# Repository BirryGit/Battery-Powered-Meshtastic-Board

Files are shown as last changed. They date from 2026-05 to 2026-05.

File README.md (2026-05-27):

# Battery-Powered-Meshtastic-Board
This is an ESP-32-S3 powered LoRa board with a battery charger. It has a connected screen and external pins for I2C and power outputs. It has ESD protection.

I want to learn how to make PCBs, and this seemed like a good idea. I wanted to make my first PCB and understand the whole process. I want to get into meshtastic, so this is awesome :)

# BOM
| Name | Purpose | Quantity | Total Cost (USD) | Link | Distributor |
|---|---|---:|---:|---|---|
| PCB | Puts Everything Together | 1 | 22.48 | https://jlcpcb.com  | JLCPCB |
| 10µF | C14 | 1 | 1.48 | https://www.digikey.com/en/mylists/list/BA1MMOEV0W/quote/18716729 | Digikey |
| LTST-C190TBKT | Leds | 3 | 1.73 | https://www.digikey.com/en/mylists/list/BA1MMOEV0W/quote/18716729 | Digikey |
| 5.1K | R1,R2 | 2 | 0.47 | https://www.digikey.com/en/mylists/list/BA1MMOEV0W/quote/18716729 | Digikey |
| 1M | R6 | 1 | 0.47 | https://www.digikey.com/en/mylists/list/BA1MMOEV0W/quote/18716729 | Digikey |
| 200k | R7 | 1 | 0.47 | https://www.digikey.com/en/mylists/list/BA1MMOEV0W/quote/18716729 | Digikey |
| 1k | R9,R10,R11 | 3 | 0.47 | https://www.digikey.com/en/mylists/list/BA1MMOEV0W/quote/18716729 | Digikey |
| BQ24040DSQR | Battery Charger | 1 | 2.85 | https://www.digikey.com/en/mylists/list/BA1MMOEV0W/quote/18716729 | Digikey |
| TLV75801PDRV | Linear Regulator | 1 | 0.93 | https://www.digikey.com/en/mylists/list/BA1MMOEV0W/quote/18716729 | Digikey |
| Buttons | Boot1,Reset1 | 2 | 0.00 | |  |
| ESP32-S3-WROOM-1 | Processor | 1 | 11.76 | https://www.digikey.com/en/mylists/list/BA1MMOEV0W/quote/18716729 | Digikey |
| 0.1µF | C13,C15 | 2 | 0.73 | https://www.digikey.com/en/mylists/list/BA1MMOEV0W/quote/18716729 | Digikey |
| USB4105-GF-A | USB C Port | 1 | 2.40 | https://www.digikey.com/en/mylists/list/BA1MMOEV0W/quote/18716729 | Digikey |
| 10k | R4,R5 | 2 | 0.47 | https://www.digikey.com/en/mylists/list/BA1MMOEV0W/quote/18716729 | Digikey |
| 540 | R8 | 1 | 0.47 | https://www.digikey.com/en/mylists/list/BA1MMOEV0W/quote/18716729 | Digikey |
| ESD7104MUTAG | ESD Protection | 1 | 3.15 | https://www.digikey.com/en/mylists/list/BA1MMOEV0W/quote/18716729 | Digikey |
| 1µF | C9,C10,C11,C12 | 4 | 2.75 | https://www.digikey.com/en/mylists/list/BA1MMOEV0W/quote/18716729 | Digikey |
| Wio-SX1262 | LoRa Module | 1 | 8.58 | https://www.seeedstudio.com/Wio-SX1262-Wireless-Module-p-5981.html | Seeed Studio |

# Pictures





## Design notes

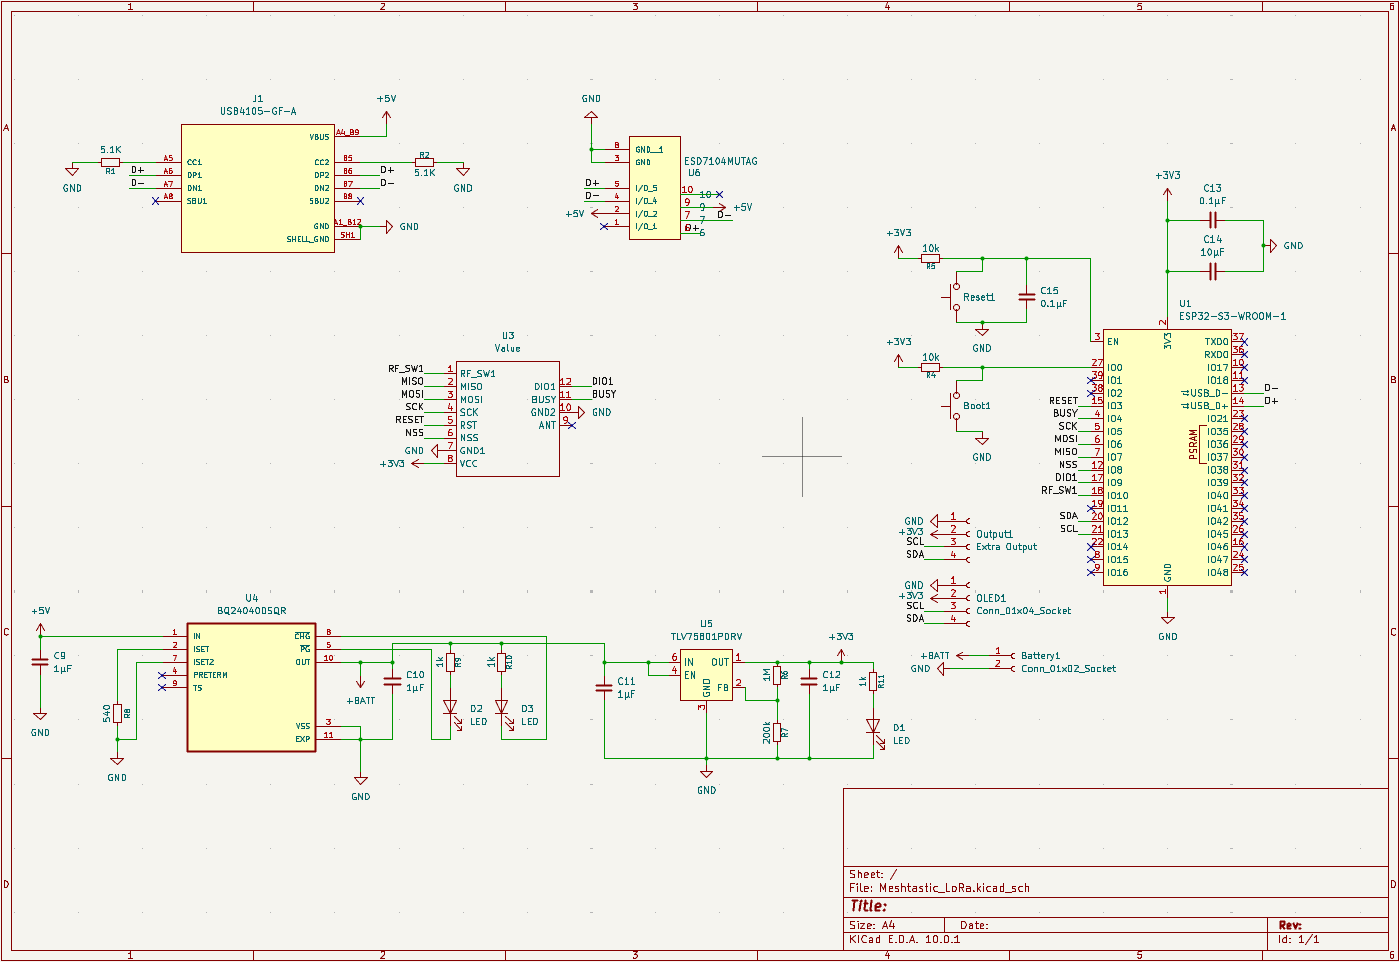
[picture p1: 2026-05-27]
Schematic/Screenshot 2026-05-26 215936.png

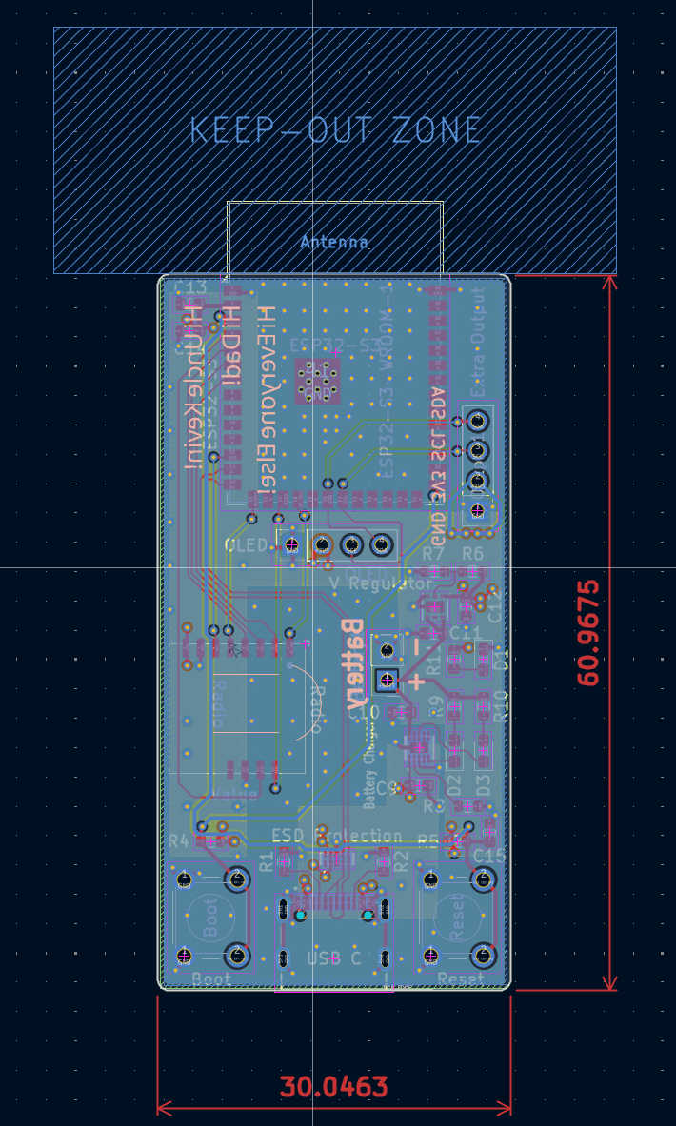
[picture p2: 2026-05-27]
PCB/Screenshot 2026-05-26 220120.png

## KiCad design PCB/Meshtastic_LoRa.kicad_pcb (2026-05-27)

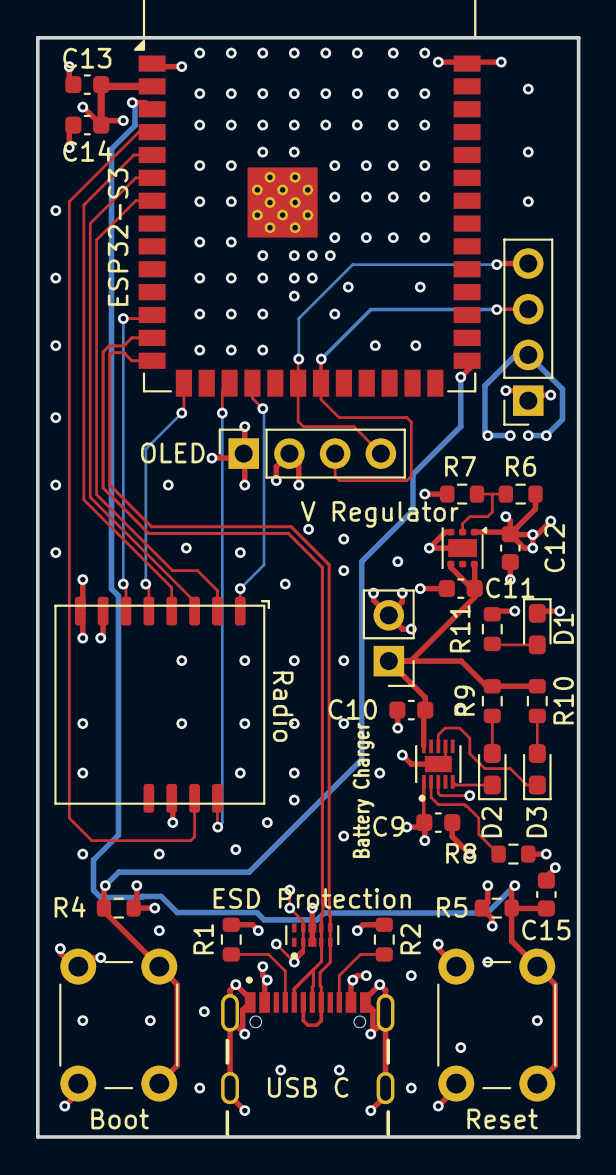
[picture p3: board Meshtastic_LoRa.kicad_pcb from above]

Board: 4 copper layers, 30.0 x 61.1 mm, 31 parts (0 on the bottom side), 27 nets.

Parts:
Battery1: Conn_01x02_Socket; PinHeader_1x02_P2.54mm_Vertical
Battery Charger: BQ24040DSQR; SON40P200X200X80-11N
Boot: SW_Push; SW_PUSH_6mm
C9, C10, C11, C12: 1µF; C_0603_1608Metric
C13, C15: 0.1µF; C_0603_1608Metric
C14: 10µF; C_0603_1608Metric
D1, D2, D3: LED; LED_0603_1608Metric_Pad1.05x0.95mm_HandSolder
ESD Protection: ESD7104MUTAG; IC_ESD7104MUTAG
ESP32-S3: ESP32-S3-WROOM-1
OLED: Conn_01x04_Socket; PinSocket_1x04_P2.54mm_Vertical
Output1: Extra Output; PinSocket_1x04_P2.54mm_Vertical
R1, R2: 5.1K; R_0603_1608Metric
R4, R5: 10k; R_0603_1608Metric
R6: 1M; R_0603_1608Metric
R7: 200k; R_0603_1608Metric
R8: 540; R_0603_1608Metric
R9, R10, R11: 1k; R_0603_1608Metric
Radio: Value; Wio-SX1262 PCB Package
Reset: SW_Push; SW_PUSH_6mm
USB C: USB4105-GF-A; GCT_USB4105-GF-A
V Regulator: TLV75801PDRV; WSON-6-1EP_2x2mm_P0.65mm_EP1x1.6mm

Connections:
+3V3: C12.2, C13.2, C14.2, ESP32-S3.2 (3V3), OLED.2, Output1.2, R4.2, R5.2, R6.1, R11.1, Radio.8 (VCC), V Regulator.1 (OUT)
+5V: Battery Charger.1 (IN), C9.2, ESD Protection.2 (I/O_2), ESD Protection.9, USB C.A4_B9 (VBUS), USB C.B4_A9 (VBUS)
+BATT: Battery1.1, Battery Charger.10 (OUT), C10.2, C11.2, R9.1, R10.1, V Regulator.4 (EN), V Regulator.6 (IN)
/BUSY: ESP32-S3.4 (IO4), Radio.11 (BUSY)
/D+: ESD Protection.5 (I/O_5), ESD Protection.6, ESP32-S3.14 (USB_D+), USB C.A6 (DP1), USB C.B6 (DP2)
/D-: ESD Protection.4 (I/O_4), ESD Protection.7, ESP32-S3.13 (USB_D-), USB C.A7 (DN1), USB C.B7 (DN2)
/DIO1: ESP32-S3.17 (IO9), Radio.12 (DIO1)
/MISO: ESP32-S3.7 (IO7), Radio.2 (MISO)
/MOSI: ESP32-S3.6 (IO6), Radio.3 (MOSI)
/NSS: ESP32-S3.12 (IO8), Radio.6 (NSS)
/RESET: ESP32-S3.15 (IO3), Radio.5 (RST)
/RF_SW1: ESP32-S3.18 (IO10), Radio.1 (RF_SW1)
/SCK: ESP32-S3.5 (IO5), Radio.4 (SCK)
/SCL: ESP32-S3.21 (IO13), OLED.3, Output1.3
/SDA: ESP32-S3.20 (IO12), OLED.4, Output1.4
GND: Battery1.2, Battery Charger.3 (VSS), Battery Charger.7 (ISET2), Battery Charger.11 (EXP), Boot.1, C9.1, C10.1, C11.1, C12.1, C13.1, C14.1, C15.2, D1.1 (K), ESD Protection.3 (GND), ESD Protection.8 (GND__1), ESP32-S3.1 (GND), ESP32-S3.40 (GND), ESP32-S3.41 (GND), OLED.1, Output1.1, R1.1, R2.2, R7.2, R8.2, Radio.7 (GND1), Radio.10 (GND2), Reset.1, USB C.A1_B12 (GND), USB C.B1_A12 (GND), USB C.SH1 (SHELL_GND), USB C.SH2 (SHELL_GND), USB C.SH3 (SHELL_GND), USB C.SH4 (SHELL_GND), V Regulator.3 (GND), V Regulator.7 (GND)
unnamed: D1.2 (A), R11.2
unnamed: D2.2 (A), R9.2
unnamed: Battery Charger.5 (~PG), D2.1 (K)
unnamed: D3.2 (A), R10.2
unnamed: Battery Charger.8 (~CHG), D3.1 (K)
unnamed: R1.2, USB C.A5 (CC1)
unnamed: R2.1, USB C.B5 (CC2)
unnamed: C15.1, ESP32-S3.3 (EN), R5.1, Reset.2
unnamed: Boot.2, ESP32-S3.27 (IO0), R4.1
unnamed: Battery Charger.2 (ISET), R8.1
unnamed: R6.2, R7.1, V Regulator.2 (FB)

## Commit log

2026-05-27 Added Gerber Files
    [Meshtastic_LoRa-B_Cu.gbr, Meshtastic_LoRa-B_Mask.gbr, Meshtastic_LoRa-B_Paste.gbr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]
2026-05-27 Moved the rest of the files to gerber
    [Meshtastic_LoRa-B_Paste.gbr, Meshtastic_LoRa-B_Silkscreen.gbr, Meshtastic_LoRa-Edge_Cuts.gbr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]
2026-05-27 Added Schematic and PCB
    [Meshtastic_LoRa.kicad_pcb, Meshtastic_LoRa.kicad_sch]
2026-05-27 Added BOM
    [BOM.csv]
2026-05-27 Updated Readme
    Added a detailed description of the battery-powered LoRa board and included a Bill of Materials (BOM) with component details.
